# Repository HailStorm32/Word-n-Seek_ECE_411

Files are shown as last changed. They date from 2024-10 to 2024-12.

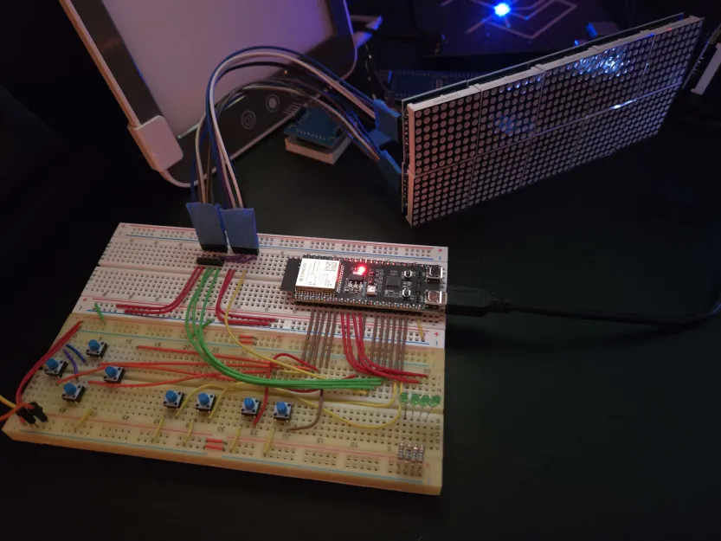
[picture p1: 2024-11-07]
Documents/Breadboard Prototype Photos/20241104_230953.webp

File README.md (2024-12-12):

## About

### Summary
This repo houses the code, board files, CAD files and documents for the ECE 411 course group project.

Word-n-Seek integrates a Wordle-style game into a small-sized arcade style gaming console, using a word retrieved from a Wordle-like API. This approach adds a unique dimension to the gameplay experience compared to using a phone or website.

The gameplay operates similarly to the popular Wordle game. Every day, the device will pull a new five-letter word from the API. The user has six attempts to guess the word, selecting letters with a buttons and confirming choices with selection keys. After each guess, the game marks correctly placed letters. The user continues guessing until either (a) they correctly guess the word or (b) they use all six attempts.

<p align="center">
Description
</p>

### Contributers
| Name | Contributions |
|---|---|
| [Bucanan Howard](https://github.com/BucananH) | PCB design and schematics developer, documentation and writing, soldering, and testing. |
| [Daniyil Kashkan](https://github.com/PeppyCode) | Documentation and writing lead, L1 diagram developer, power system design and construction, soldering, and testing. |
|[Demetri Van Sickle](https://github.com/HailStorm32) | Programming lead, GitHub and team manager, GPIO, display & game logic code. |
| [Mohammed Alreshoud](https://github.com/MohammedAlreshoud) | Documentation and writing, 3D design developer and console box constructor. |
| [Wallace McKenzie](https://github.com/Poly-guru)  | Programming, L0 diagram developer, Wordle API & Wi-Fi connection providing and testing. |

<br>

### Open Source Libs Used
- [max7219 Driver](https://github.com/UncleRus/esp-idf-lib/tree/master/components/max7219)
- [cJSON](https://github.com/DaveGamble/cJSON)

<br>
<br>

## Setup

### ESP-IDF Framework
Follow the directions on the [ESP-IDF wiki](https://docs.espressif.com/projects/esp-idf/en/v5.0/esp32s3/get-started/index.html#ide) on how to setup the environment

> Note: Use version 5.0 or greater

### "Wordle" API
Create a free account for the [Wordle Game API](https://rapidapi.com/azizbergach/api/wordle-game-api1) to gain an API key

> Note: the free tier only allows 60 requests/day

> Upgrading to the "pro" tier will allow for 5000 requests/day for $5

### Code
Code is under the `Code` directory. Open VS Code(or your preferred editor) in this directory for best results.

Create headers called `hidden.h` in the following directories and format as follows.

#### Components/apiControl/include

    #define  API_KEY  "api_key_string_here"

#### Components/wifiControl/include

    #define  WIFI_SSID  "ssid_string_here"
    #define  WIFI_PASS  "password_string_here"

<br>
<br>

## Use

### Buttons
Description

There are four small white directional buttons. Two for LEFT and RIGHT movement of the cursor. Press and hold either to slide the cursor left or right 
As well as two buttons for increasing and decreasing the screen brightness.

Four colored action buttons are to the right of the directional buttons, and are for SELECT, GUESS, DELETE and EXIT. These buttons will selectively light up when you are able to press them.

### Operation
Once the game starts, you will be able to add and delete letters to construct a five letter word (see [Modes](https://github.com/HailStorm32/Word-n-Seek#modes)). 

Once you are satisfied with your word guess, press GUESS to submit your word. The results screen on the bottom row will then update to display the which letters are correct (see [Results](https://github.com/HailStorm32/Word-n-Seek#results)). 

You have six guesses before the game ends. If you reach six guesses without guessing correctly, the results row will be replaced with what the word was supposed to be. The game is now over, press EXIT to exit.

If you guess the word before you use up all six guesses, the results screen will show all correct (see [Results](https://github.com/HailStorm32/Word-n-Seek#results)). The game is now over, press EXIT to exit.

### Modes

#### Startup
Once the device is powered up you will be greeted with the Word n Seek start screen. 

Press SELECT to start the game. Once the game is started, you will be in letter edit mode.

#### Edit Letters
Use the LEFT and RIGHT buttons to move the cursor left or right.

When the cursor is over the desired spot, press SELECT to enter letter select mode to place a letter at that spot, OR press DELETE to delete the selected letter.

#### Letter Selection
In this mode use the LEFT and RIGHT buttons to move the cursor and the letter carousel left and right.

Press SELECT to select the highlighted letter and return to letter edit mode.

Press DELETE to exit letter selection and return to letter edit mode without placing a letter.

### Results
In letter edit mode, the bottom row of the screen will show which letters are correct, incorrect, or are in the wrong place. Below are the possible symbols and what they mean.

#### Unknown
Description

State of letter is unknown
> Before your first guess, the result row will consist of all unknowns ('?')

#### Correct
Description

States that the letter is correct and in the right spot
<br>

#### Incorrect
Description

States that the letter is incorrect and not in the word
<br>

#### Swap
Description

States that the letter is correct, but in the wrong spot

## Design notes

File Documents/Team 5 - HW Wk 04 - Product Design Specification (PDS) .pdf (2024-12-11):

ECE 411
Andrew Greenberg
10/20/2024

## Team 5 Product Design Specification (PDS)

Bucanan Howard, Daniyil Kashkan, Demetrius Van Sickle, Mohammed Alreshoud, and Wallace McKenzie

Project Name

Word-n-Seek Game

Executive Summary with Concept of Operations

The Word-n-Seek design integrates a Wordle-style game into a small-sized arcade style gaming console, using a word retrieved from a Wordle-like API. This approach adds a unique dimension to the gameplay experience compared to using a phone or website.
The gameplay operates similarly to the popular Wordle game. Every day, the device will pull a five-letter word from the API. The user has six attempts to guess the word, selecting letters with arrow keys and confirming choices with selection keys. After each guess, the game marks correctly placed letters and removes incorrect letters. The user continues guessing until either (a) they correctly guess the word or (b) they use all six attempts.
Part of the screen will display a simplified “Wordle grid” with six rows (one per guess) and five columns (one per letter). The grid will use red, green, and blue to indicate incorrect, correct, and unguessed letters, respectively.

Market Analysis

The target customers for this product are casual gamers, word puzzle enthusiasts, and fans of Wordle who are seeking a console version they can use at their desk. Competition will come from smartphone apps, websites offering similar word puzzle games, and multi-purpose portable gaming consoles. This product distinguishes itself by offering a focused and immersive gaming experience through a physical device dedicated solely to playing Wordle. The novelty of a desktop game version of Wordle will appeal to both collectors and a casual audience much like similar tabletop arcade cabinets. Priced between $50 and $85, it remains affordable while incorporating essential components such as a screen, controllers, and Wi-Fi / Bluetooth modules. This makes it accessible to a wide audience while delivering a unique and enjoyable experience.

Requirements

- Must display words to the user.
- Must allow the user to add and delete letters.
- Must generate a new word to guess every day.
- Must have two forms of input.
- Must be able to turn on / off the device.
- Must not overheat on failure.
- Should have arrow keys.
- Should have multiple buttons.
- Should run off a 12V 2A DC supply.
- Should provide internal regulation to 5V 2A DC.
- Should have a timed mode.
- Should be able to broadcast the website for the user to configure Wi-Fi connection.
- May be portable, i.e., work as a desktop or handheld device.
- May shock the user on failure.
- May have a console box made of cedar, for the smell and aesthetics, or poplar, depending on expense.
- May have other game modes other than Wordle.
- May operate off battery power.
- May have a sleep mode.
- May have light-up buttons.
- May have an on/off switch.
- May give audible feedback in the form of tones / buzzes.

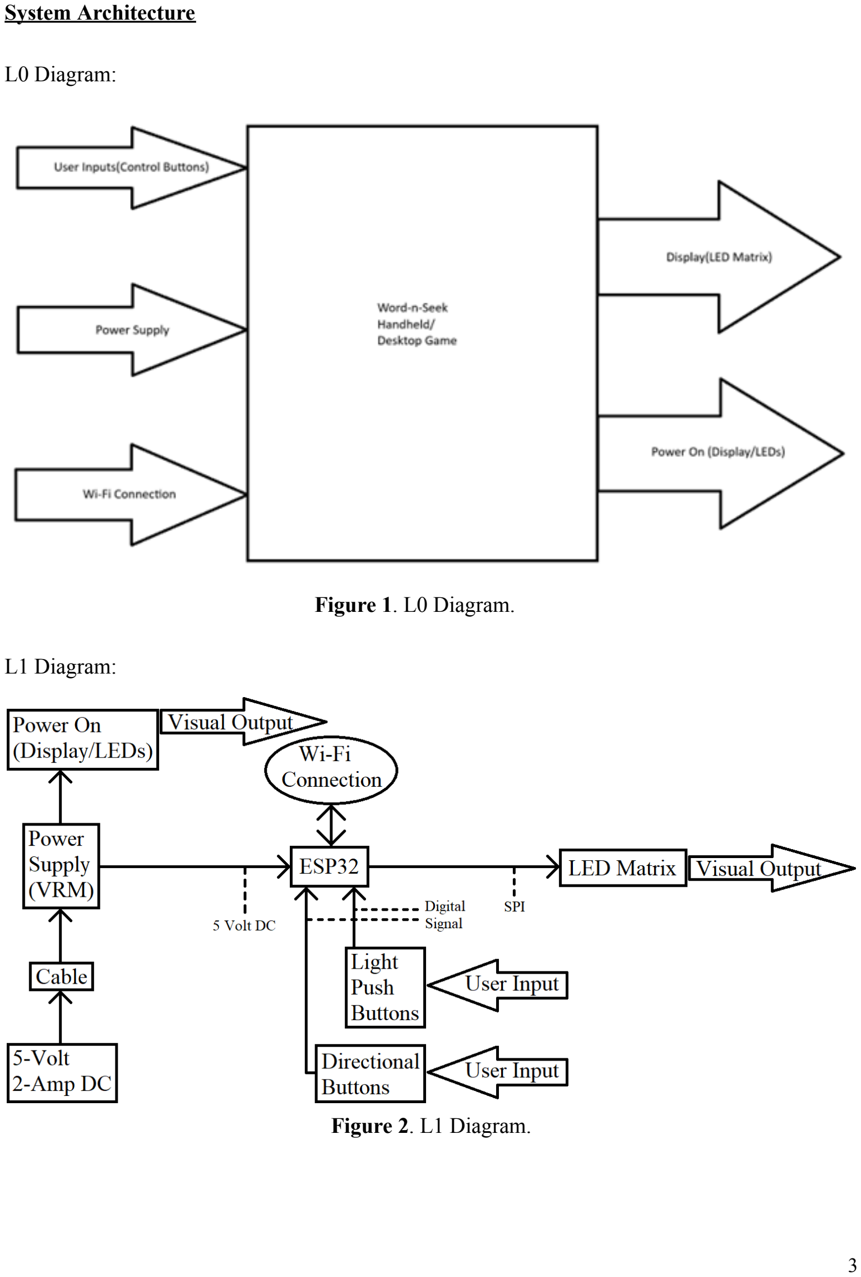
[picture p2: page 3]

System Architecture

L0 Diagram:

Figure 1. L0 Diagram.

L1 Diagram:

Figure 2. L1 Diagram.

Design Specification

Processor:

- ESP32-S3

Sensors:

- Arcade buttons
- Simple 4-way arrow key buttons
- No particular brand, there are a ton on Amazon.

Actuator:

- 10x EC Buying 8x8 LED matrix displays
- This particular display is driven by the max7219 chip and allows for easy daisy chaining of display modules. An LED matrix was chosen over an LCD panel due to time constraints and the available bandwidth of our team's coders. An LED matrix is easier to design graphics for than an LCD.

Power:

- 12V 2A DC regulated to 5V 2A DC

Development Environment:

- ESP-IDF framework

Enclosure:

- Wood or 3D-printed plastic case

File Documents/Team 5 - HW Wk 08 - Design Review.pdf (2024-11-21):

ECE 411
Andrew Greenberg
11/19/2024

## Team 5 Design Review

Bucanan Howard, Daniyil Kashkan, Demetrius Van Sickle, Mohammed Alreshoud, and Wallace McKenzie

First Design Review with Team 2 - 8:00 pm - 9:08 pm - Meeting Notes:

> Little to no negative feedback. PCB Traces look good. Everything looks straightforward.
> Positive feedback on the schematic design, with inquiries about its size and potential improvements. > Overall comment: “Good job!”
> Suggested to add switch main power rail.
> Should have 1uF labeled on decoupling cap on ESP32S3.
> Should add a note about having onboard USB on dev board.

Second Design Review with Team 7 - 9:30 pm - 10:11 pm - Meeting Notes:

> Voltage threshold 1.2 volts.
> Suggested labeling screen dimensions directly on the schematic for clarity and reference.
> Suggested labeling buttons on the schematic; e.g., |_ Adding "boxes" (label above buttons) > Add test points to the schematic??

Feedback for Team 5 (us) from Team 2

- GND should be labeled with 1.5 Farad (note for Bucanan).
- Label onboard USB for the PCB (also note for Bucanan).
- Overall no negative feedback, keep up the good work.
- Everything is straightforward, nothing extra or unnecessary.
- The on/off switch can be added directly to the PCB.
- However, Daniyil will stick with designing a separate circuit for testing purposes.

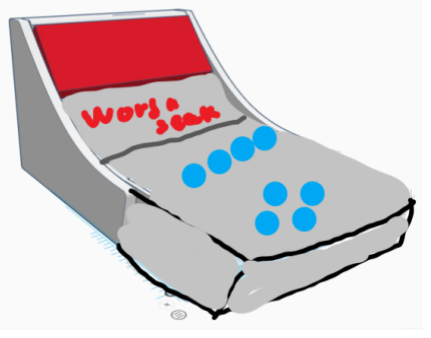
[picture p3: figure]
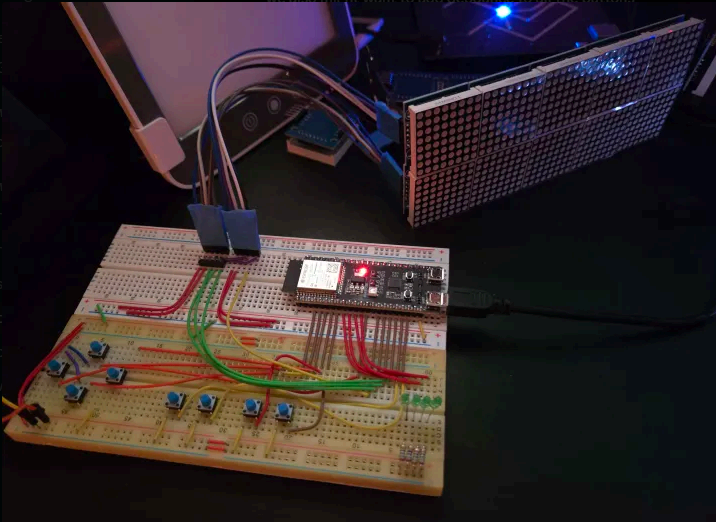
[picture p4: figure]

Figure 1. Figures shared by Team 5.

1

Feedback for Team 2 (from us to them)

- Pretty clear schematic to look at and ready.
- Specific roles defined. Every member seems caught up on the design and their own parts.
- The team also ran into plenty of problems, like proper power distribution.
- Resolved everything properly.
- Safeguards put into place like a power-off state in case of current issues.
- OLED ground makes sense, something else Bucanan found does not.
- Another OLED bit referenced questionably (NOT AN ISSUE).
- The battery can only be charged twice or three times.
- Systems are put into place to check fresh batteries against garbage batteries.
- Bucanan recommended adding fuses or Zener diodes to ensure proper 12 Volt flow (??)
- Last note: the buck converter handles most of the voltage regulation.
- The fan is always on. As long as the master switch is closed, the fan is on (always).
- It takes a couple hours to charge a battery (estimated 2 hours).
- You cannot push a battery too much while charging it, as it might break.
- Active high input. For safety, if the ESP32 fails, the active high input goes down.
- Recommendation by Bucanan: Implement a hardware failsafe.
- (exclusively software failsafes implemented now).
- List VTN for the transistors. Rename schematic ports for clarity.
- Add a current limiting diode between VCC and sensitive components.

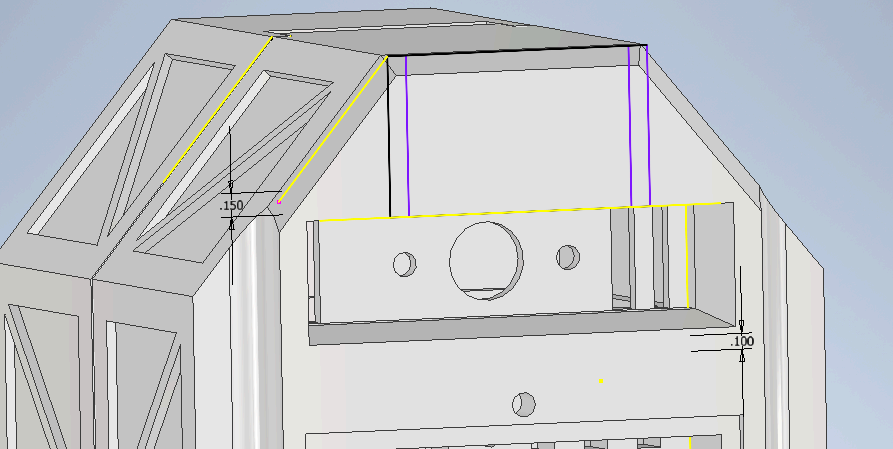
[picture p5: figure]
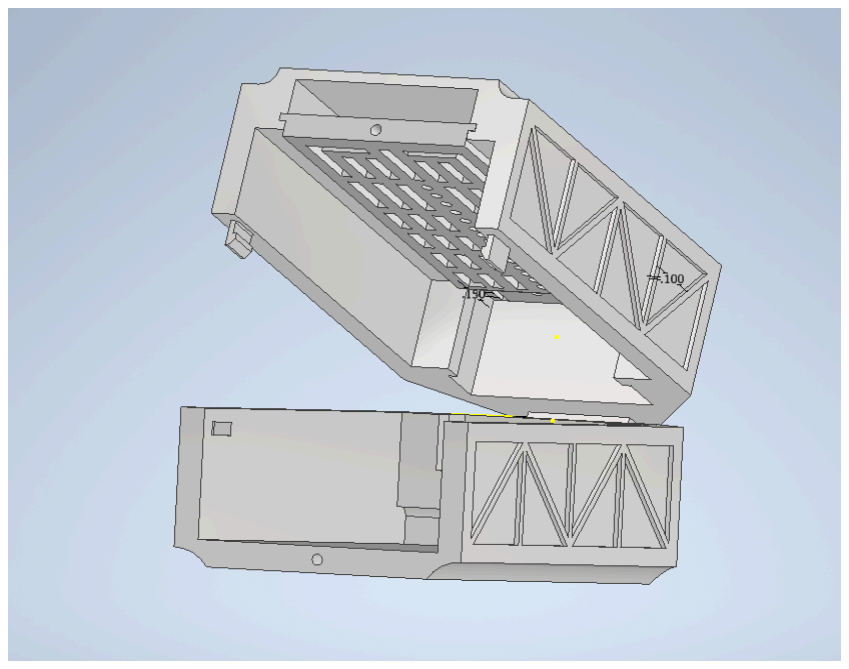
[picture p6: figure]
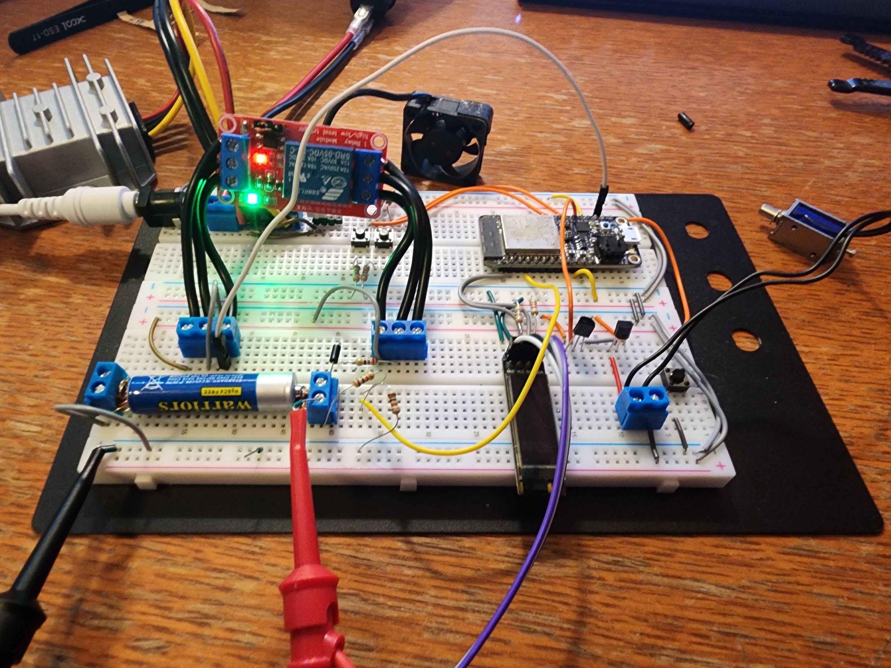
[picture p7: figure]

Figure 2. Figures shared by Team 2

Feedback for Team 5 (us) from Team 7

- Power distribution needs more defining.
- The threshold is 1.5V.
- Add a label above the buttons (recommended by Annika).

2

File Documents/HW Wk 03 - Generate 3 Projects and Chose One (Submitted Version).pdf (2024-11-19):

Bucanan Howard
Daniyil Kashkan
Demetrius Van Sickle
Mohammed Alreshoud
Wallace McKenzie
ECE 411
Andrew Greenberg
10/15/2024

Team 5 Practicum Project Progress Report: Generate Three Projects and Choose One

Three initial project ideas:
#1. Anti Drone Device (Drone Swatter)

#2. Air Filter System

#3. Handheld Wordle Game (Handle)

Descriptions of each project idea:

Project #1 Name: Anti Drone Device (Drone Swatter)
Project #1 Description:
Drone Swatter is a drone detection and deterrence system that uses targeted radio frequency (RF) analysis to identify and disrupt nearby drones by detecting telemetry signals commonly used for drone communication within the 2.4 GHz and 5 GHz frequency bands. When a drone is detected within a specified proximity, an alert is generated with an option to jam the drone’s control signal by broadcasting broadband white noise, temporarily disabling its operation by tampering with its pathfinding and connection.
Project #1 Concept of Operation:
Detection: The system remains idle while on and continuously scans for signals on 2.4 GHz and 5 GHz frequencies, typical of drone telemetry and control.
Telemetry Decoding: When a suspected drone signal is detected, the system attempts to decode its telemetry data to assess proximity and direction.
User Alert: If a drone is detected, the system alerts the user through an audible and visual signal. Optional Jamming: With user initiation, the system transmits a controlled broadband noise signal to jam drone control, providing a secure perimeter around sensitive areas.
Project #1 Components:
Sensors
1) Software-Defined Radio (SDR):
HackRF One: Well-suited SDR, covering a wide frequency range (1 MHz to 6 GHz), including both 2.4 GHz and 5 GHz bands, and allowing full-duplex communication. It will be the primary device for capturing telemetry signals, decoding data, and initiating detection protocols.

2) Antennas:
Dual-Band Antenna (2.4 GHz and 5 GHz): A single dual-band antenna enhances signal detection for both frequency bands, simplifying the design while ensuring coverage.
Yagi Directional Antenna: This directional antenna is used for precise detection and tracking of the drone’s approach direction, improving system responsiveness.
Controller
ESP32-S3 Microcontroller: The ESP32-S3 offers both Wi-Fi and Bluetooth capabilities, making it ideal for managing the SDR, performing initial signal processing, and controlling alert and jamming functions. It provides reliable data handling and control at a low cost, integrating well with the HackRF One and antennas.
Actuators
1) Broadband Noise Generator:
Mini-Circuits ZX93-2500+ Noise Source: This high-power noise source generates broadband white noise on the target bands (2.4 GHz and 5 GHz). Paired with the appropriate directional antennas, it provides efficient jamming capabilities when the user activates this mode.
2) Power Amplifier Module:
RF Power Amplifier (2.4 GHz and 5 GHz compatible): Boosts noise signal to ensure effective jamming within the desired radius, thus maintaining signal integrity during jamming.
3) User Alert System:
Buzzer: Emits audible alert when a drone is detected within range, ensuring prompt notification. LED Indicator Panel: Provides a visual signal strength indication, giving the user an immediate sense of proximity and detection status.

Project #2 Name: Air Filter System
Project #2 Description:
The purpose of the air filter system is to identify problems with air quality and initiate a dual filtration process to enhance the surrounding environment. To monitor air contaminants and modify the filtration rate accordingly, it uses a collection of sensors. With the help of an ESP32 microcontroller, the system can be operated automatically or by the user over Wi-Fi in real-time monitoring. The system has an LCD screen that provides real-time feedback on system status and air quality levels. Air is filtered through two layers of cloth.
Project #2 Concept of Operation:
Detection: The system continuously monitors the air for pollutants such as dust, gasses, and humidity. It remains idle until pollutant levels rise above a certain threshold.
Sensor Readings: Once a pollutant is detected, ESP32 reads data from the sensors and evaluates the air quality levels. The system determines whether filtration needs to be activated or adjusted. User Alert and Control: The system can alert the user via Wi-Fi notifications and display real-time air quality data on the LCD screen. The user can control the system manually or allow automatic filtration adjustment based on sensor data.

Filtration Control: The air is passed through two cloth filters, a coarse filter and a fine filter to remove larger particles and fine pollutants. The system dynamically adjusts the airflow using motor control relays based on the severity of contaminants. Filtration continues until safe air quality levels are restored.
Project #2 Components:
Sensors:
Air Quality Sensor (MQ-135): Detects various harmful gasses like CO2

, ammonia, and benzene.
Humidity and Temperature Sensor (DHT22): Monitors the air's humidity and temperature to adjust filtration speed and ensure optimal performance.
Controller:
ESP32 Microcontroller: Manages sensor data, processes air quality information, controls motor, provides Wi-Fi connectivity for remote monitoring, and communicates with the LCD screen. Actuators:
Fan Motor: Adjusts the airflow rate to filter out pollutants based on the sensor readings.
Relay Modules: Controls the activation and power levels of the filtration fan, allowing precise control over the filtering process.
Display Screen:
(16x2 or 20x4) LCD Display: Shows live air quality and pollutant levels, humidity, temperature, system status, and alerts. ESP32 refreshes data on this display continuously so that the user will have explicit visual feedback about air quality conditions.
Filtration Components:
Air Filter Cloth: First Layer: The first layer is the intake of air, which catches larger particles like dust, making it the front line of defense in the system.
Second Layer: It is at the air outlet and further strengthens the filtration by catching the finer particles to ensure only clean air is released.

Project #3 Name: Handheld Wordle Game (Handle)
Project #3 Description:
The Handheld Wordle Game would, in operation, take a word from the Wordle API and use it for a Wordle-style game built into a handheld gaming console. It brings a level of dimensionality to the phone game, and would enable us to add extra features to spice up Worlde itself. The game requires a built in screen, speakers, controllers/keyboard and a case. The system connects to the Wordle API either through Wi-Fi or through a phone Bluetooth connection and takes the daily Wordle word, which it then uses to play a word guessing game with the user.
Project #3 Concept of Operation:
Boot Up: Upon powering on the device, the handheld will prompt the user with the option to play today's Wordle game and to display their longest streak.
Getting Today's Wordle Word: After selecting to play a game, the ESP32 will use either Wi-Fi or bluetooth to connect to Wordle’s free API in order to grab a random five-letter word. The screen will then display five blank boxes.

Gameplay: Using the dials and keyboard, users will type a five-letter word and hit enter. The ESP32 will then compare that word against the daily word and use colored squares on the graphical display to communicate to the user which letters are incorrect, which letters are correct, and which letters are in the word but in the wrong spots.
Finishing the Game: Once the user guesses the word or runs out of chances, the game will end, and if the user was successful, the game will increase their win streak. If they fail, the streak will be reset instead.
Project #3 Components:
Sensors:
Push Button Switches: A switch network will be used to create a controller or keyboard interface that the user will utilize to interact with the game.
TE Connectivity / Alcoswitch: (https://www.mouser.com/manufacturer/alcoswitch/) A Potentiometer dial such as the TE Alcoswitch can be implemented in order to work as a selection wheel or menu scroll wheel.
Controller:
ESP32-S3 Microcontroller: The ESP32-S3 offers options for Wi-Fi and Bluetooth, both possible ways to connect to the Wordle API in order to get the daily word. The ESP32-S3’s flexibility and ease of programming will give us room to integrate both software and hardware features. Moreover, the non-volatile memory storage of the ESP32 will be beneficial in storing streaks and high scores.
Actuators:
Adafruit 1.9" 320x170 Color IPS TFT Display - ST7789: A colored screen is necessary for the functionality of a Wordle game, and the screen will show the number of remaining guesses, which letters are in the correct spots, and which letters are incorrect.
CVS-1508 Speakers: Add tactile sound feedback when a correct letter is selected, the word is guessed correctly, or the player loses the game.
28821 Coin Vibration Motor: A motor can be used to add a physical rumble feature to the game that, coupled with the sound, will provide a more exciting video-game experience for the user. Power:
9V Battery Snaps & Contacts 9V PCB MOUNT: The 9 volt battery casing attached to the back of the device will power the screen, ESP32, and sensors. A rechargeable 9 volt battery should provide enough mA hours to power the handheld for up to 6 hours.
DC-to-DC Converter: Not all modules on the board will require the same amount of power. So, where necessary, an appropriate DC-to-DC converter will be selected to meet those power needs.

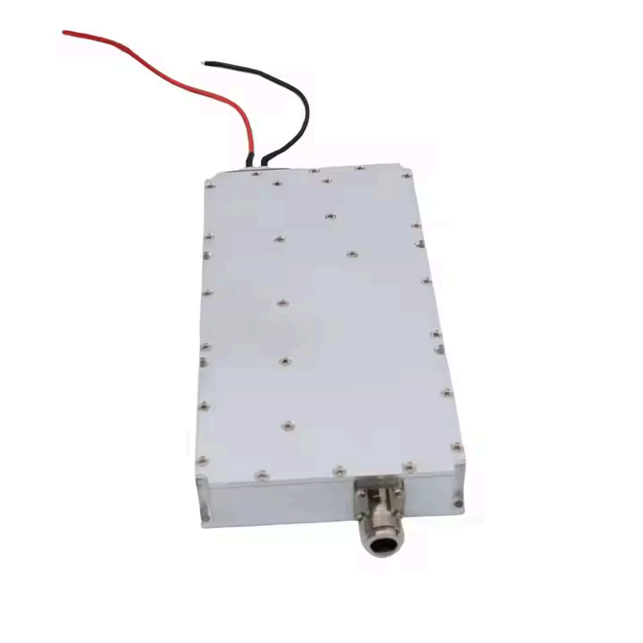
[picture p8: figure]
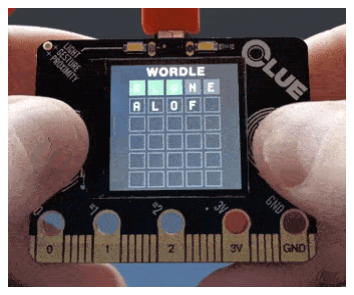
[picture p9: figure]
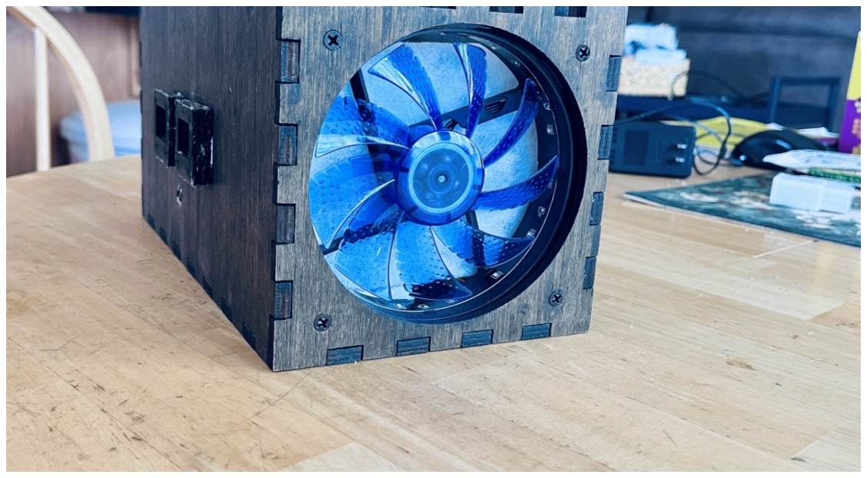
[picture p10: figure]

Figure 1. Project #1 | Figure 2. Project #2 | Figure 3. Project #3

Ultimately, the final project idea we have chosen to build is the Handheld Wordle Game. We passed on the Anti Drone Device project idea because it sounded too sophisticated and challenging to be completely implemented in the remaining seven weeks of the term, and it would require the availability of a drone which none of us have. We passed on the Air Filter System project idea because it did not sound challenging enough, as several members of the group already worked on similar projects, and a couple even designed and built air filter systems previously as part of the ECE 212 course. The Handheld Wordle Game is a new and unique project idea never designed by any team member, so it is an evenly fresh experience for us to implement using the disciplined design process taught in class and the available skills .

Finally, we came up with unique names: Handle for our project, Handle Builders for our team, and Handheld Wordle Game for our code repository.

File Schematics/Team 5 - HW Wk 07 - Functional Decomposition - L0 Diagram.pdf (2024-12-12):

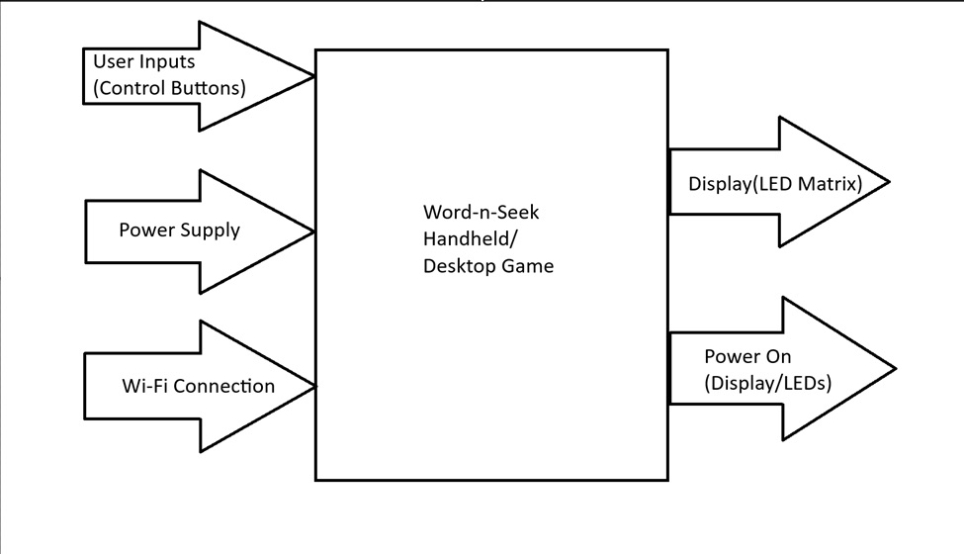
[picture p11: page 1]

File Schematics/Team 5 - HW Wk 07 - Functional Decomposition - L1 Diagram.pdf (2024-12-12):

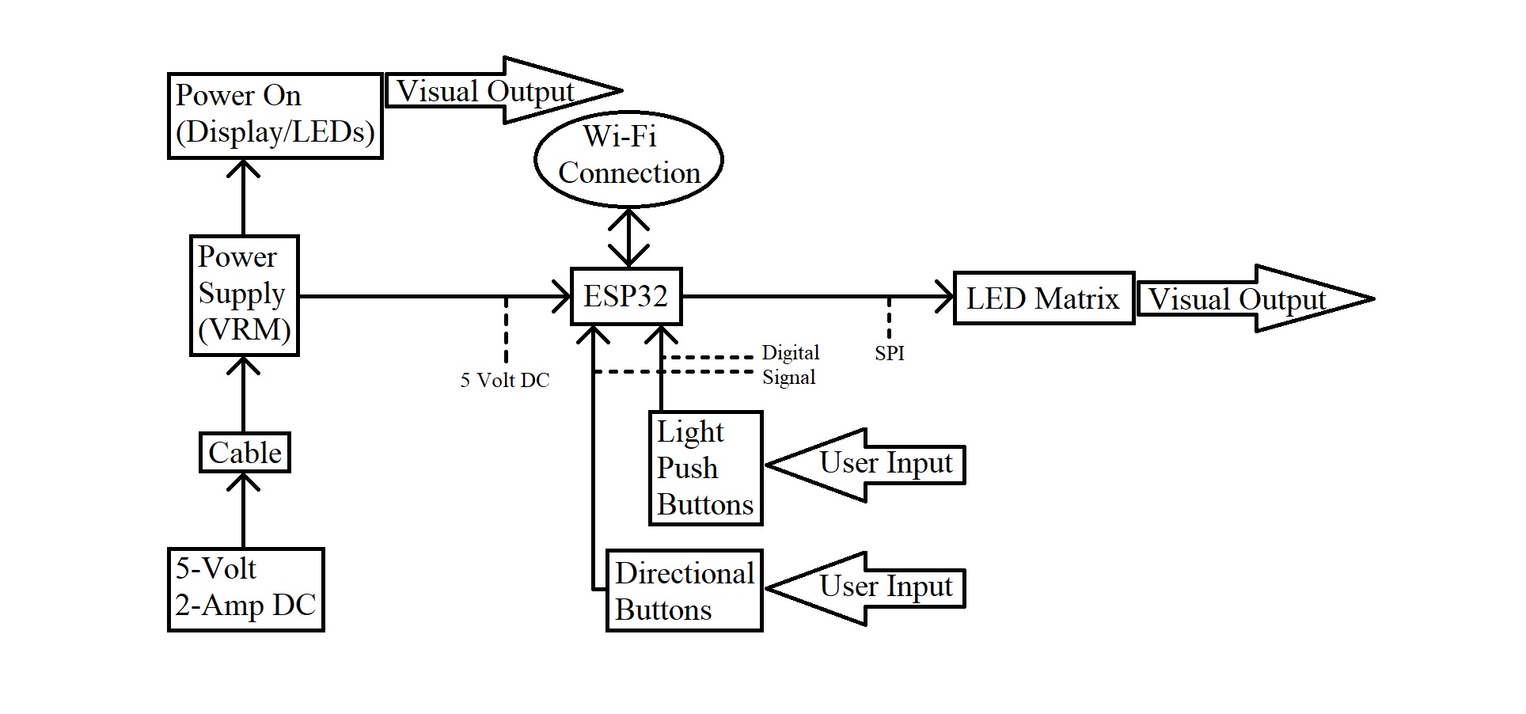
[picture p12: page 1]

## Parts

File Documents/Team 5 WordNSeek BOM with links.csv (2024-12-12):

# | Unique Name | P/NP | Manufacturer | Manufacturer Pin Number | Description | Distributor | Distributor Pin Number | Price Per Unit | Quantity | Total Cost | Link
1 | .1 uF Cap | P | Comchip | CAPP_0402_M | Capacitor | TAIYO YUDEN | 963-MAASL105CC7105MF | $0.10 | 2 | $0.20 | https://www.mouser.com/ProductDetail/TAIYO-YUDEN/MAASL105CC7105MFCA01?qs=HFfMDpzxxd1Fn%2FInbJA7vw%3D%3D
2 | 0603 Diode | P | Comchip | DIODE_0603 | Diode | TAIYO YUDEN | 750-CDBU0145-HF | $0.32 | 1 | $0.32 | https://www.mouser.com/ProductDetail/Comchip-Technology/CDBU0145-HF?qs=2qJf6qQ4IOKJ1QV5aOB4hg%3D%3D
3 | 5V 2A Power Supply | P | CUI INC | PJ-002A | Power supply barrel jack for DC power | Same Sky | 490-PJ-002A | $0.70 | 1 | $0.70 | https://www.mouser.com/ProductDetail/Same-Sky/PJ-002A?qs=WyjlAZoYn51CKfAix9Mngw%3D%3D&mgh=1&gad_source=1
4 | 5 pin Header | P | Samtec | TSW-105-23-G-S | Connector Header Through Hole 5 position 0.100 (2.54mm) | Samtec | 200-TSW10523GSLL | $0.58 | 10 | $5.80 | https://www.mouser.com/ProductDetail/Samtec/TSW-105-23-G-S-LL?qs=rU5fayqh%252BE0mHsi8oUSlPQ%3D%3D
5 | Jumper | P | Samtec | MTLW-101-24-G-D-210 | Connector Header Through Hole 2 position | Samtec | 200-MTLW10124GD210 | $0.48 | 3 | $1.44 | https://www.mouser.com/ProductDetail/Samtec/MTLW-101-24-G-D-210?qs=rU5fayqh%252BE2sZjyn6To4eg%3D%3D
6 | 7 Nmos Stack | P | TI | DRV777DR | 20-V, 7- bit Integrated Motor and Relay Driver | Texas Instruments | 595-DRV777DR | $0.48 | 1 | $0.48 | https://www.mouser.com/ProductDetail/595-DRV777DR
7 | ESP32 | P | Espressif | ESP32-S3-DEVKITC-1-N8R2 | WiFi Development Tools - 802.11 (Engineering Samples Only) ESP32-S3 General-Purpose Development Board, ESP32-S3-WROOM-1-N8R2, with Pin Header | Espressif Systems | 356-E32-S3DVKTC1N8R2 | $15.00 | 1 | $15.00 | https://www.mouser.com/ProductDetail/Espressif-Systems/ESP32-S3-DevKitC-1-N8R2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
8 | 8x8 MAX7219 Dot Matrix Display | P | EC Buying | N/A | 8x8 Dot Matrix Display | Amazon | N/A | $1.08 | 10 | $10.80 | https://a.co/d/9yggITk
9 | 24mm LED Illuminated Push Button | P | EG Starts | N/A | 24mm LED Illuminated Push Button | Amazon | N/A | $2.40 | 5 | $12.00 | https://a.co/d/87GFwCD
10 | 30mm LED Illuminated Push Button | P | EG Starts | N/A | 30mm LED Illuminated Push Button | Amazon | N/A | $2.38 | 5 | $11.90 | https://a.co/d/aKY7UUA
11 | 3-D Printed enclosure | P | EPL | N/A | 3-D Printed (enclosure) - Multiple parts | EPL | N/A | $38.24 | 1 | $38.24
12 | PCB | P | OSH park | N/A | Our PCB design | OSH park | N/A | $30.13 | 1 | $30.13
 |  |  |  |  |  |  |  |  | Total Cost: | $127.01

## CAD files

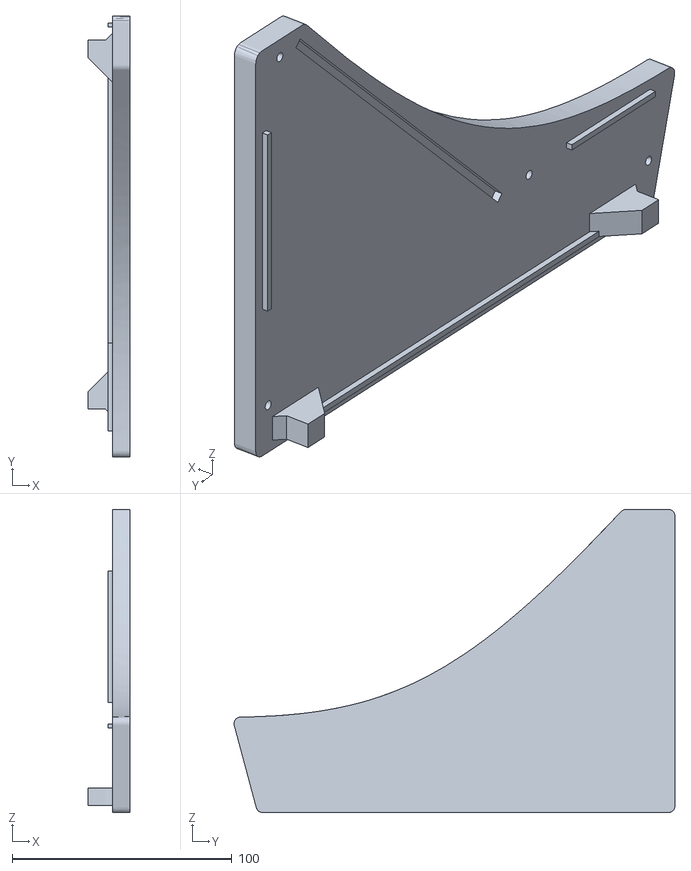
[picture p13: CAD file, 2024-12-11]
3D_Closure/Right_panel.stl
19.0 x 200.7 x 138.0

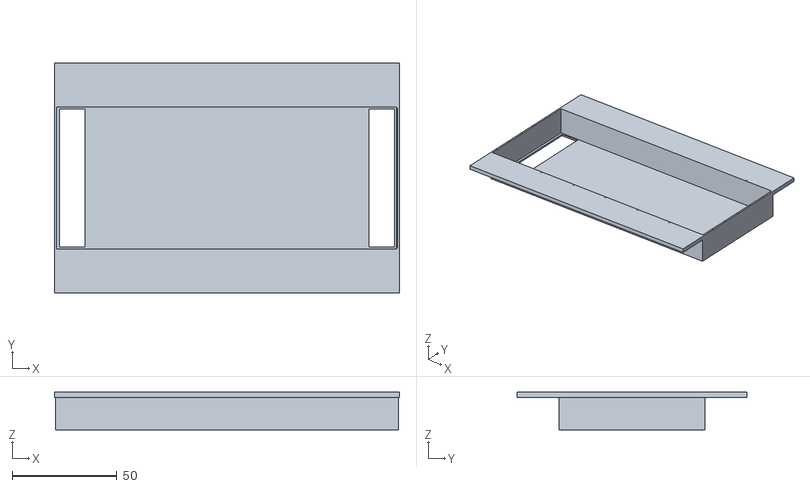
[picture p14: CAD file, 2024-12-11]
3D_Closure/ScreenMountVer2.stl
165.0 x 110.0 x 18.0

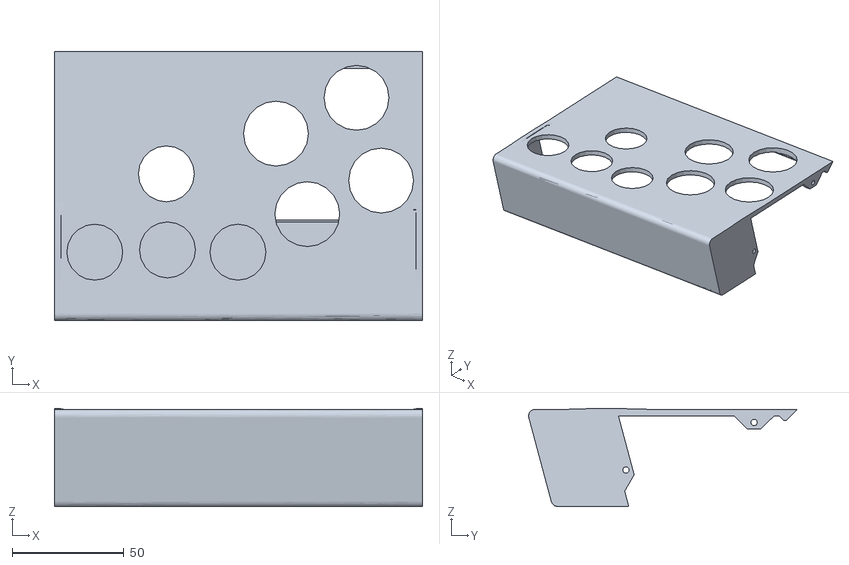
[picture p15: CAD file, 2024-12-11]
3D_Closure/Controller_ver2.stl
164.5 x 120.1 x 43.8

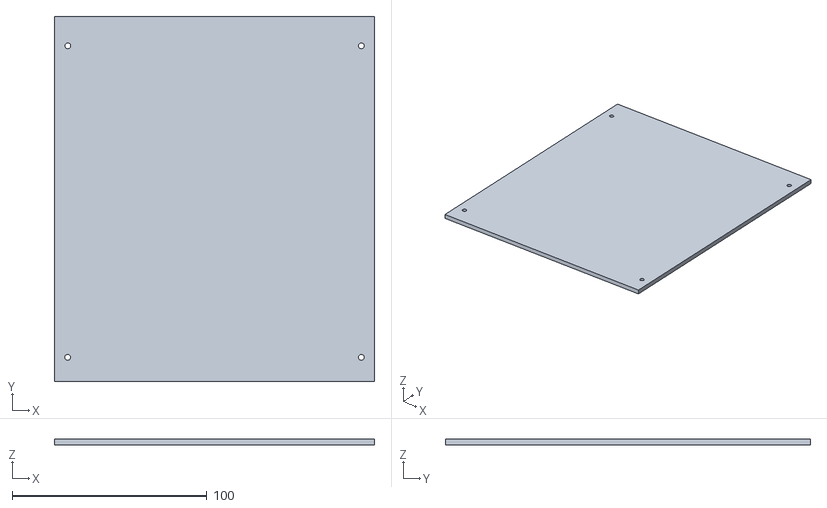
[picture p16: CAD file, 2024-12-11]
3D_Closure/Bottom_panel.stl
164.5 x 187.8 x 3.00

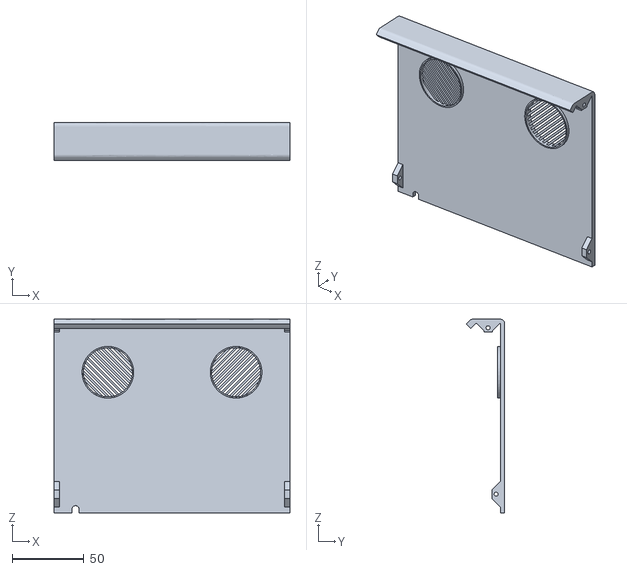
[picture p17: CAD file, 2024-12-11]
3D_Closure/Back panel.stl
164.5 x 26.8 x 135.0

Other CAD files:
3D_Closure/Left_panel.stl

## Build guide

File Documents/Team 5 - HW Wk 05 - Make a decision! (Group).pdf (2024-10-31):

ECE 411
Andrew Greenberg
10/27/2024

## Team 5 Make a Decision Assignment

Bucanan Howard, Daniyil Kashkan, Demetrius Van Sickle, Mohammed Alreshoud, and Wallace McKenzie

1. To choose a proper display for our project design, we use the Decision Matrix and Analytical Hierarchy Process (AHP) methodologies as tools to make a final decision based on the types of displays and desired characteristics.
2. Decision Matrix:

The matrix in Figure 1 shows the comparison of five display options across six criteria: Brand Name, Cost, Safety, Design, Power Consumption, and Ease of Coding. Each option is rated and weighted to produce a final score.

| Medium 16x32 RGB LED matrix panel - 6mm Pitch (Adafruit) | 0.91 inch OLED I2C SSD1306 LED DC Display (Arduino) | 2.8" SPI TFT LCD Display Touch Panel ILI9341 240x320 (XIITIA) | 10x 8x8 LED matrix display (EC Buying) | I2C IIC 1602 LCD Display Module 16x02 (Hosyond)
Brand-name | 1 | 5 | 5 | 2 | 4 | 3
Cost | 3 | 1 | 5 | 2 | 3 | 4
Safety | 2 | 4 | 3 | 3 | 4 | 3
Design | 5 | 4 | 3 | 4 | 4 | 4
Power Consumption | 4 | 3 | 1 | 1 | 5 | 1
Ease of Coding | 5 | 5 | 1 | 1 | 5 | 1
Score | | 73 | 50 | 43 | 86 | 50
Figure 1. Decision Matrix.

3. AHP:

The table in Figure 2 shows pairwise comparisons among criteria to establish their relative importance, resulting in weights that reflect each criterion’s priority in the decision process.

Figure 2. Analytical Hierarchy Process (AHP).

The expanded Decision Matrix in Figure 3 evaluates each display option under each criterion using AHP pairwise comparisons, generating a ranking based on the weighted criteria.

| Medium 16x32 RGB LED matrix panel - 6mm Pitch (Adafruit) (https://www.adafruit.com/product/420) | 0.91 inch OLED I2C SSD1306 LED DC Display (Arduino) (https://www.amazon.com/HiLetgo-Serial-Display-SSD1306-Arduino/dp/B01N0KIVUX) | 2.8" SPI TFT LCD Display Touch Panel ILI9341 240x320 (XIITIA) (https://www.amazon.com/XIITIA-Display-ILI9341-240x320-Screen/dp/B0CJHTMPXF) | 10x 8x8 LED matrix display (EC Buying) (https://www.amazon.com/EC-Buying-MAX7219-Electronic-Microcontroller/dp/B0BXDNCVRT) | I2C IIC 1602 LCD Display Module 16x02 (Hosyond) (https://www.amazon.com/Hosyond-Display-Module-Arduino-Raspberry/dp/B0BWTFN9WF?th=1)
Brand-name | 0.12 | 0.371 | 0.028 | 0.054 | 0.438 | 0.11
Cost | 0.09 | 0.10 | 0.38 | 0.12 | 0.19 | 0.21
Safety | 0.21 | 0.21 | 0.20 | 0.19 | 0.21 | 0.19
Design | 0.05 | 0.22 | 0.44 | 0.15 | 0.09 | 0.11
Power Consumption | 0.26 | 0.44 | 0.11 | 0.22 | 0.09 | 0.15
Ease of Coding | 0.27 | 0.15 | 0.22 | 0.44 | 0.11 | 0.09
Score | | 0.26 | 0.19 | 0.24 | 0.17 | 0.14
Figure 3. Expanded Decision Matrix.
| Brand-name | Cost | Safety | Design | Power Consumption | Ease of Coding | Mean | Weight
Brand-name | 1 | 7 | 1/9 | 2 | 1/2 | 1/2 | 0.9 | 0.12
Cost | 1/7 | 1 | 2 | 2 | 1 | 1/9 | 0.6 | 0.09
Safety | 9 | 1/2 | 1 | 2 | 1/2 | 2 | 1.4 | 0.21
Design | 1/2 | 1/2 | 1/2 | 1 | 1/9 | 1/5 | 0.4 | 0.05
Power Consumption | 2 | 1 | 2 | 9 | 1 | 1 | 1.8 | 0.26
Ease of Coding | 2 | 9 | 1/2 | 5 | 1 | 1 | 1.9 | 0.27
Fraction values are in the Calc sheet (https://docs.google.com/spreadsheets/d/1eQpPgmgjUxQAnvneXPUD6lUV1ERm-a3i-iPEuT672x0/edit?gid=1924139799) | | | | | | | | 1.00

| Medium 16x32 RGB LED matrix panel -6mm Pitch (Adafruit) | 0.91 inch OLED I2C SSD1306 LED DC Display (Arduino) | 2.8" SPI TFT LCD Display Touch Panel ILI9341 240x320 (XIITIA) | 10x 8x8 LED matrix display (EC Buying) | I2C IIC 1602 LCD Display Module 16x02 (Hosyond) | Brand name rating
Medium 16x32 RGB LED matrix panel -6mm Pitch (Adafruit) | 1 | 7 | 5 | 1 | 7 | 0.371
0.91 inch OLED I2C SSD1306 LED DC Display (Arduino) | 1/7 | 1.00 | 1/5 | 1/7 | 1/7 | 0.028
2.8" SPI TFT LCD Display Touch Panel ILI9341 240x320 (XIITIA) | 1/5 | 5 | 1 | 1/9 | 1/5 | 0.054
10x 8x8 LED matrix display (EC Buying) | 1 | 7 | 9 | 1 | 9 | 0.438
I2C IIC 1602 LCD Display Module 16x02 (Hosyond) | 1/7 | 7 | 5 | 1/9 | 1 | 0.11

Figure 4. Finalized AHP based on the display options.

4. The results from the Decision Matrix and finalized AHP show that the 10x 8x8 LED matrix display (EC Buying) is the preferred display option for our project. Thus, we got the same result from both the Decision Matrix and the AHP methodologies.

In evaluating the display options, we focused on six key criteria: Brand Name, Cost, Safety, Design, Power Consumption, and Ease of Coding, each weighted to fit our technical and project needs. Brand Name was considered for reliability and ease of support, but it held less weight than direct performance factors. Cost had a moderate weight, allowing us to stay within budget without sacrificing essential features. Safety took into account factors like durability and electrical protection, scoring higher for displays with added resilience. Design influenced the display’s usability and fit within the project, with considerations for screen clarity, size, and ease of physical integration. Power Consumption was highly prioritized, as efficient power usage is essential for battery-operated projects, and alternatives were scored based on current draw and power-saving capabilities. Ease of Coding was weighted heavily, as it affects development time and integration reliability, so displays that offered robust libraries and compatibility with our programming environment scored higher. This balance of criteria helped us pick a display that meets both our technical requirements and practical constraints.

To come up with the tables, we followed the recommendations to use Google Sheets and insert the tables into a Google Doc. The Google Sheet tables can be found by following this link: https://docs.google.com/spreadsheets/d/1eQpPgmgjUxQAnvneXPUD6lUV1ERm-a3i-iPEuT672x0/edit?gid=0#gid=0. (https://docs.google.com/spreadsheets/d/1eQpPgmgjUxQAnvneXPUD6lUV1ERm-a3i-iPEuT672x0/edit?gid=0#gid=0)

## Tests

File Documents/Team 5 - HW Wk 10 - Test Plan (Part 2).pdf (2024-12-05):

Test Case

Test Author: Team 5
Test Case Name: | Power Supply Testing | Test ID #: | PS-TC-01
Description: | Using Bifurcation, and a current limited lab power supply use the onboard jumpers to safely test power delivery to all sections of the circuit | Type: | □ white box □ black box □ ________

Tester Information
| Name of Tester: | Bucanan Howard | Date: | 12/4/24
| HW/SW Version: | Ver 4/ Ver 1.0 | Time: | 6:00 PM
| Setup: | Variable PSU, board with buttons and display
S T E P | Action | Expected Result | P A S S | F A I L | N / A | Comments
1 | No Jumpers, Barrel Jack Plugged in | 5 V on cathode of the diode | das
2 | Jumper to ESP32 plugged in | 5V at Power pin of ESP 32, current draw increased | ass
3 | Jumper to Screens Plugged in | Screens power on, current draw increased | asd | | | Reset required to see image on screen
4 | Plug in Select Button | Onboard LED on buttons turns on | | 123 | | Vcom on Nmos stack incompatible with power supply
5 | Probe Button signal pin in | 3.3 volts on each button data pin | 123
6 | Connect all jumpers and start game | Display lights up at full brightness as do button LEDs | | 1233 | | Increase current limit to 250 mA Pass on re-test
| Overall test result: | | 123 | | | Core functionalities power as specced, hardware change required for the button LEDs
2024-12-04 | Page 1 of 3

Matrix Test (for varying parameters)

Test Author: Team 5

Test Case Name: | Directional Button Functions | Test ID #: | DB-MT-01
Description: | Test that the 4 directional buttons function as intended. | Type: | □ white box □ black box □ _____________

Tester Information

| Name of Tester: | Demetri Van Sickle | Date: | 12/4/24
| HW/SW Version: | 4.0/1.0 | Time: | 6:40pm
| Setup: | 4 directional buttons, main board, 5V supply, display
T E S T | INPUTS | EXPECTED OUTPUTS | P A S S | F A I L | N / A | Comments
1 | Select button pressed at reboot | Start screen transitions to game screen | 12
2 | Select button pressed at game | Select screen entered | 12
3 | Exit Button Pressed | Game exits | 12
4 | Left Button Pressed | Cursor scrolls left | 12
5 | Right Button Pressed | Cursor scrolls right | 12
6 | Up Button Pressed | Screen Brightness Increases | 12 | | | Double check schematic for silk screen assignments
7 | Down Button Pressed | Screen Brightness Decreases | 12
| Overall test result: | | 12

Test Case

Test Author: Team 5
Test Case Name: | On/Off Switch Testing | Test ID #: | SW-TC-02
Description: | Test that the voltage regulator correctly regulates all incoming voltage to output 5 Volts DC, that the on/off switch properly functions and activates and/or deactivates the ESP32 based on its position, and that the LEDs provide proper feedback for incoming wall voltage connection and switch position. | Type: | □ white box □ black box □ ________

Tester Information
| Name of Tester: | Daniyil Kashkan | Date: | 12/4/24
| HW/SW Version: | Ver 4/ Ver 1.0 | Time: | 7:20 PM
| Setup: | 12V cable converter, 5V voltage regulator, LEDs with resistors, on/off switch (7101J1V3QE2 C&K)
S T E P | Action | Expected Result | P A S S | F A I L | N / A | Comments
1 | Plug Cable into a 120V AC Wall Socket | 120V AC converted to 5V 2A DC; first LED lights up | das | | | Converted to 12V 2A DC, which is acceptable
2 | Flip the Switch Position | Closes or opens the connection; second LED turns on/off | das
3 | Probe Voltage Regulator | Takes in 12V (from step 1), outputs 5V at all times | asd | | | Minimum of 7V input required
4 | Probe the ESP32 | Turns on when switch is closed and off when switch is opened | das | | | Requires 7V min for proper 5Vin
5 | Disconnect Wall Socket Cable | The entire device, including both LEDs, shuts off | das
| Overall test result: | | das | | | All tests correctly passed, switch circuit ready to be applied to the rest of the device

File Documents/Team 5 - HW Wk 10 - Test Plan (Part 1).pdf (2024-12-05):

ECE 411
Andrew Greenberg
12/01/2024

## Team 5 Test Plan

Bucanan Howard, Daniyil Kashkan, Demetrius Van Sickle, Mohammed Alreshoud, and Wallace McKenzie

# Part 1

### Unit Tests

- Test power supply provides 5V
- Test ESP32-S3 powers on
- Test WiFi module powers up
- Test that all matrix displays powerup
- Test that when buttons are pressed it pulls the input to GND
- On/Off switch test

### Verification Tests

- Test SELECT button starts new game on powerup
- Test SELECT button selects letter under cursor
- Test LEFT button moves the cursor left
- Test RIGHT button moves the cursor right
- Test DELETE button deletes letter under cursor in letter edit mode
- Test the WiFi module that it connects and disconnects
- Test the LED module on the matrix lights up
- Test the game if it detects winning or losing

### Validation Tests

- Test if SELECT button switches to letter select mode when pressed in letter edit mode
- Test if SELECT button switches to letter edit mode when pressed in letter edit mode
- Test GUESS button submits word for verification from either letter edit or letter select mode
- Test DELETE button only functions when in letter edit mode
- Test EXIT button quits the game from any mode
- Test the game ends when all attempts have been used the display will show you the correct solution
- Test the system accurately tracks the number of attempts
- Test the system if it automatically advances to the next round after a win or a loss

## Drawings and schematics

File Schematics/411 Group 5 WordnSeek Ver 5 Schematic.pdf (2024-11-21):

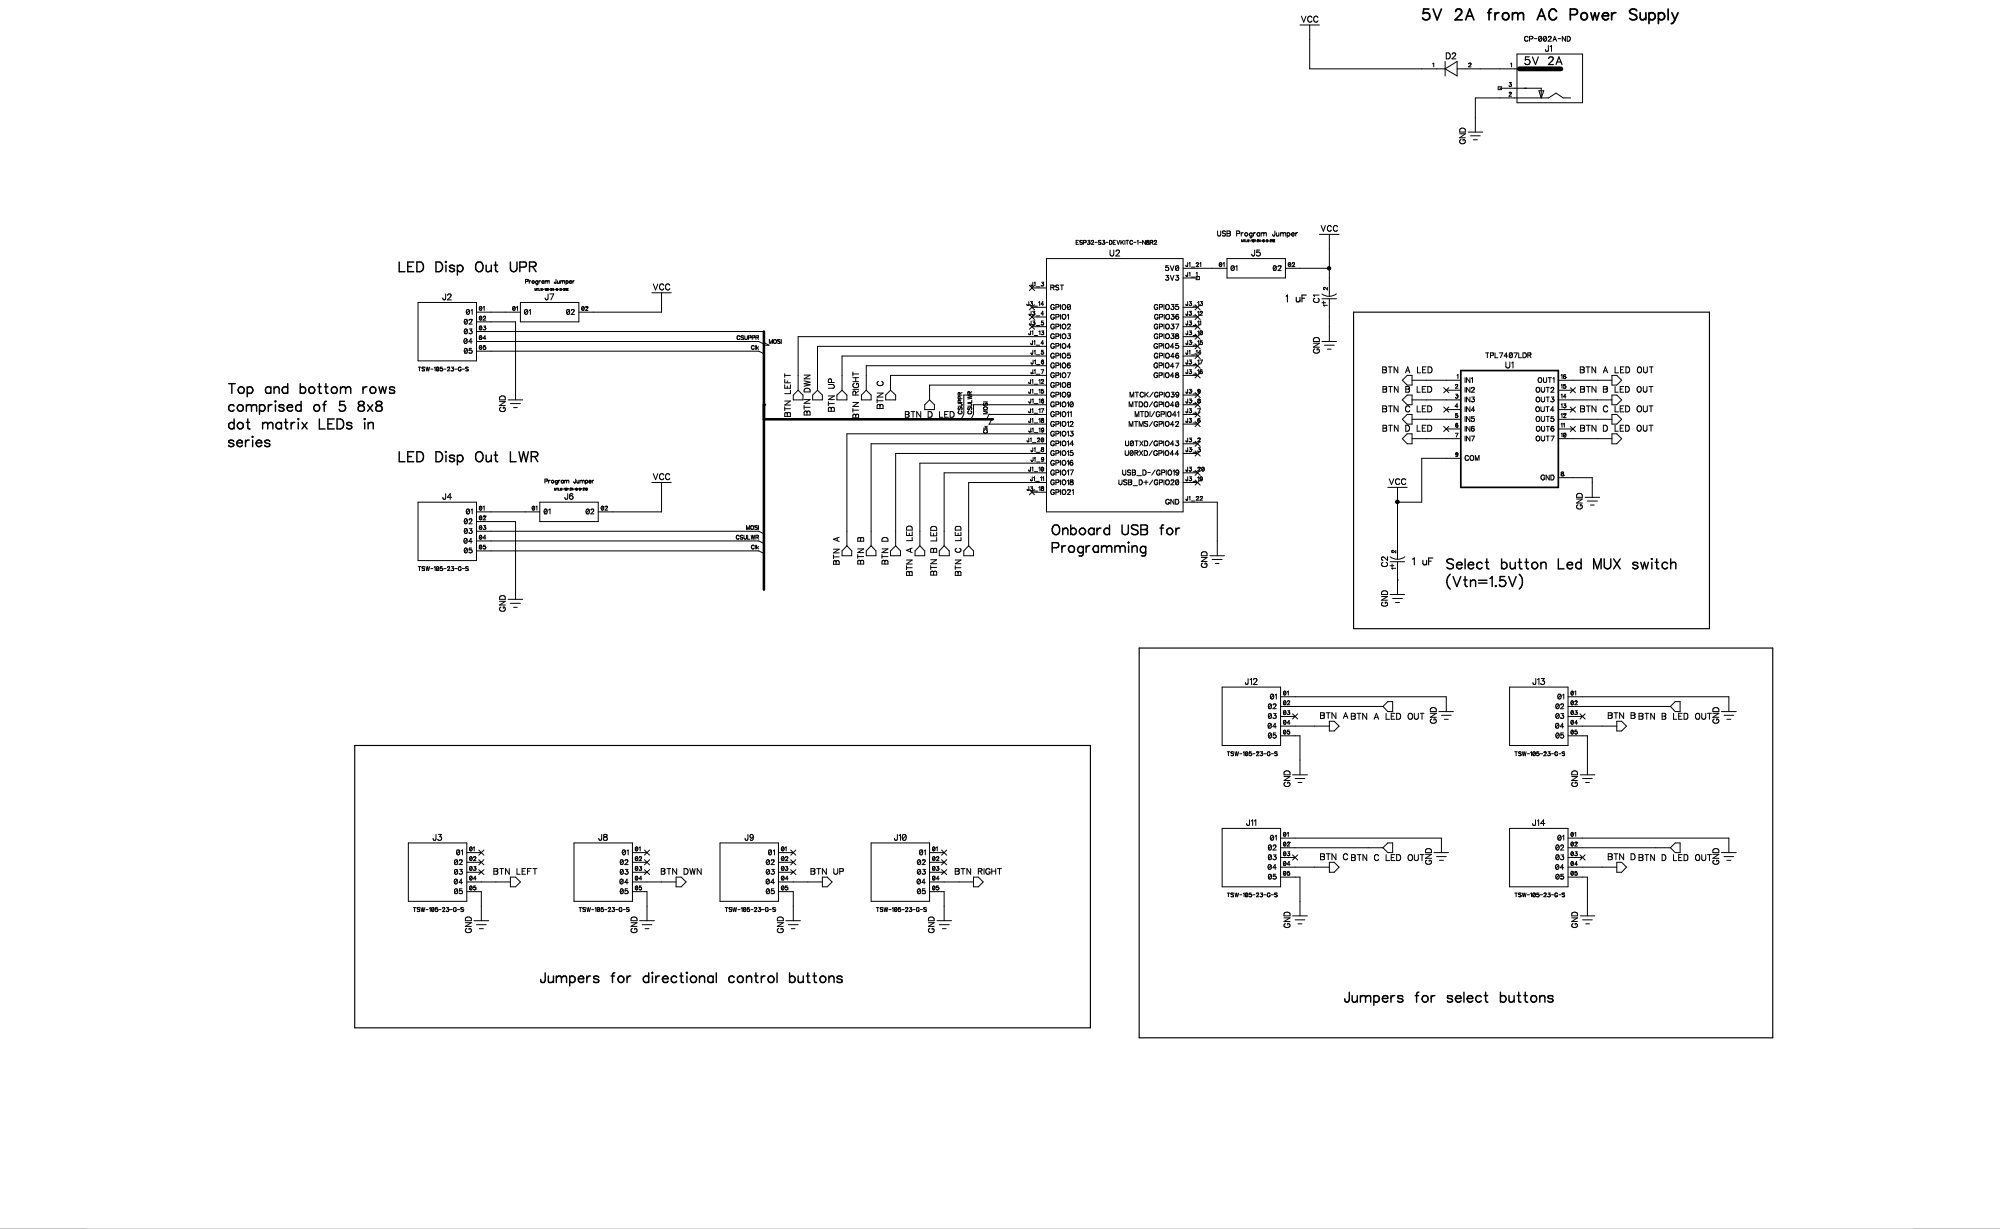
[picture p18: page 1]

Top and bottom rows
comprised of 5 8x8
series

BTN BBTN B LED OUTGND

BTN DBTN D LED OUT

Jumpers for select buttons

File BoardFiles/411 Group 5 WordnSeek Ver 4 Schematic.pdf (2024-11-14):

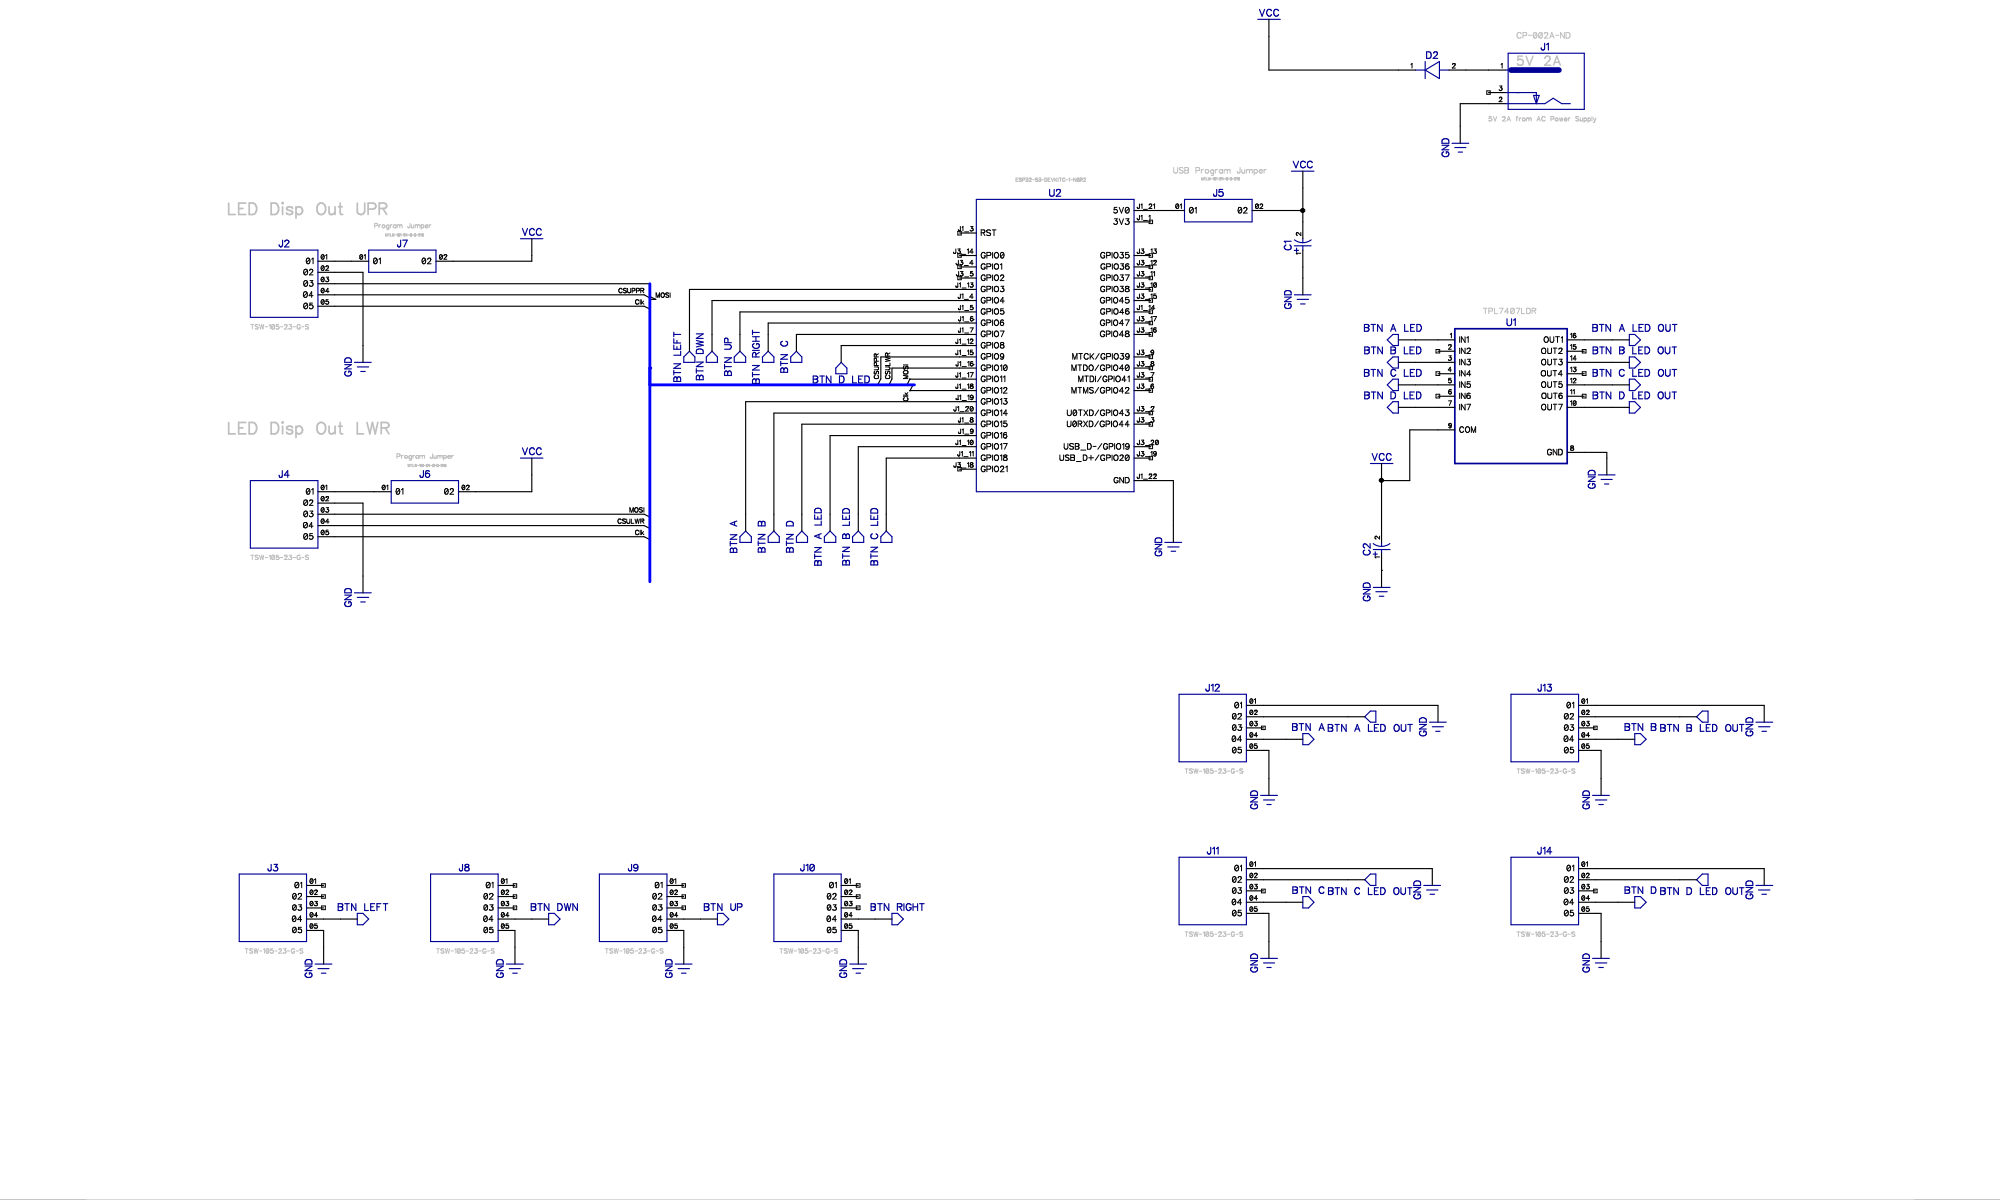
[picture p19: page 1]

5V 2A from AC Power Supply

BTN BBTN B LED OUTGND

BTN DBTN D LED OUT

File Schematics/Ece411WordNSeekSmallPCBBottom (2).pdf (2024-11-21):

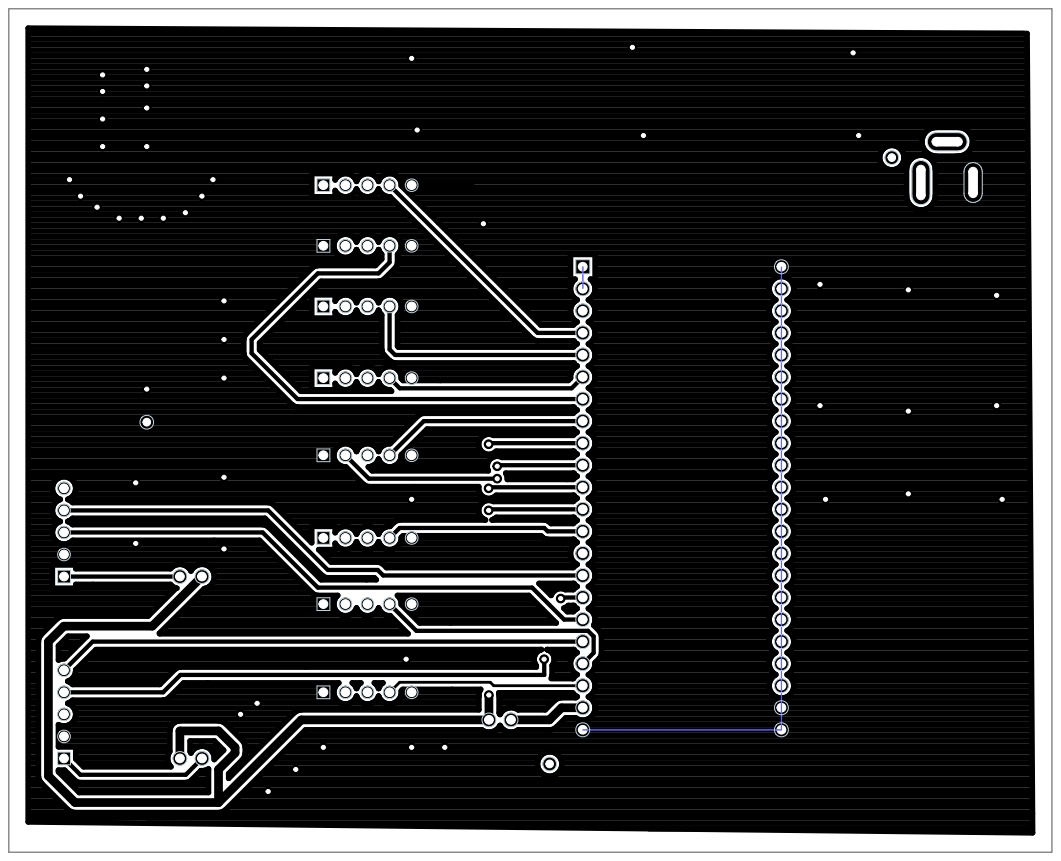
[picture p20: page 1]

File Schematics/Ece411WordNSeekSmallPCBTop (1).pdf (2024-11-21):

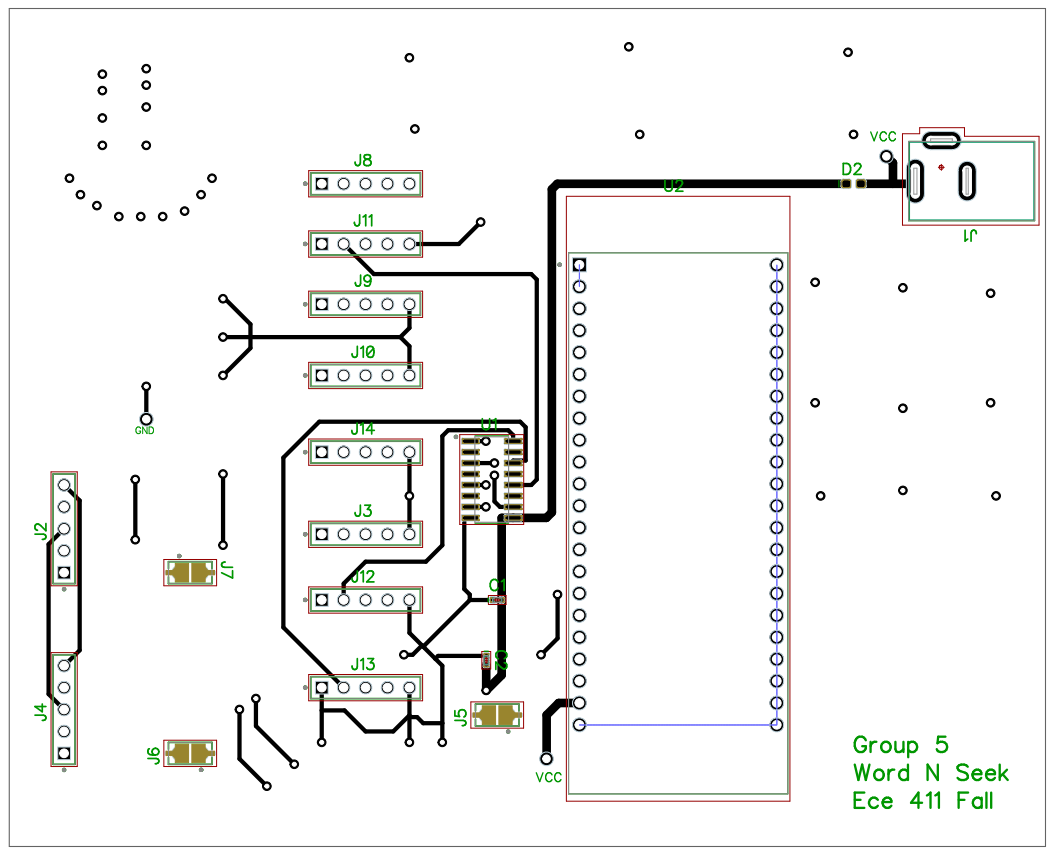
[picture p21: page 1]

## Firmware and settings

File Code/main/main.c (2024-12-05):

#include "esp_log.h"
#include <gpioControl.h>
#include <wifi.h>
#include "api_client.h"
#include <matrixDisplay.h>
#include <wordGuessGame.h>

#define LOG_TAG  "main"

int app_main(void)
{
    initGPIO();
    ESP_LOGI(LOG_TAG, "ESP32 WiFi Station");
    wifi_init_sta();
    api_client_init();
    display_init();  
    ESP_LOGI(LOG_TAG, "Boot successful");
    
    wordGuessGameStart();

    return 0;
}

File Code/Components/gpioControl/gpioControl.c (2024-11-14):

#include "esp_log.h"
#include "gpioControl.h"

/*-----------------------------------------------------------
Literal Constants
------------------------------------------------------------*/

//Create a bit masks to select the GPIO pins we want
#define GPIO_OUTPUT_PIN_SEL ((1ULL<<GPIO_BTN_A_LED) | (1ULL<<GPIO_BTN_B_LED) | (1ULL<<GPIO_BTN_C_LED) | (1ULL<<GPIO_BTN_D_LED))
#define GPIO_INPUT_PIN_SEL  ((1ULL<<GPIO_JOY_LEFT) | (1ULL<<GPIO_JOY_RIGHT) | (1ULL<<GPIO_JOY_UP) | (1ULL<<GPIO_JOY_DOWN) | (1ULL<<GPIO_BTN_A) | (1ULL<<GPIO_BTN_B) | (1ULL<<GPIO_BTN_C) | (1ULL<<GPIO_BTN_D))

#define ESP_INTR_FLAG_DEFAULT 0

#define DEBOUNCE_TIME_MS 200


#define LOG_TAG "gpio_control"


/*-----------------------------------------------------------
Macros
------------------------------------------------------------*/

#define TICKS_TO_MS(ticks) (ticks * portTICK_PERIOD_MS)

/*-----------------------------------------------------------
Types
------------------------------------------------------------*/

/*-----------------------------------------------------------
Gobals
------------------------------------------------------------*/

QueueHandle_t gpioEventQueue = NULL;

/*-----------------------------------------------------------
Statics
------------------------------------------------------------*/

uint64_t s_lastTime;

/*-----------------------------------------------------------
Local Function Prototypes
------------------------------------------------------------*/

static void IRAM_ATTR gpioIsrHandler(void* arg)
{
    uint32_t gpio_num = (uint32_t) arg;
    uint64_t curMS = TICKS_TO_MS(xTaskGetTickCountFromISR());

    //To debounce the button, we will only send the event if the last event was more than DEBOUNCE_TIME_MS ago
    if(curMS - s_lastTime > DEBOUNCE_TIME_MS)
    {
        xQueueSendFromISR(gpioEventQueue, &gpio_num, NULL);
    }

    s_lastTime = curMS;
}

/*-----------------------------------------------------------
Functions
------------------------------------------------------------*/

esp_err_t initGPIO()
{
    gpio_config_t ioConf = {}; 
    esp_err_t ret = ESP_OK;

    //initialize the timer
    s_lastTime = 0;

    //disable interrupt
    ioConf.intr_type = GPIO_INTR_DISABLE;
    //set as output mode
    ioConf.mode = GPIO_MODE_OUTPUT;
    //bit mask of the output pins
    ioConf.pin_bit_mask = GPIO_OUTPUT_PIN_SEL;
    //disable pull-down mode
    ioConf.pull_down_en = 0;
    //disable pull-up mode
    ioConf.pull_up_en = 0;
    //configure GPIO with the given settings
    ret |= gpio_config(&ioConf);

    //interrupt of rising edge
    ioConf.intr_type = GPIO_INTR_NEGEDGE;
    //bit mask of the input pins
    ioConf.pin_bit_mask = GPIO_INPUT_PIN_SEL;
    //set as input mode
    ioConf.mode = GPIO_MODE_INPUT;
    //enable pull-up mode
    ioConf.pull_up_en = 1;
    ret |= gpio_config(&ioConf);

    if(ret != ESP_OK)
    {
        ESP_LOGE(LOG_TAG, "Error setting up GPIO pins");
        return ret;
    }
    
    //create a queue to handle gpio event from isr
    gpioEventQueue = xQueueCreate(10, sizeof(uint32_t));

    //install gpio isr service
    ret |= gpio_install_isr_service(ESP_INTR_FLAG_DEFAULT);

    //hook up isr handler for each pin
    ret |= gpio_isr_handler_add(GPIO_JOY_LEFT, gpioIsrHandler, (void*) GPIO_JOY_LEFT);
    ret |= gpio_isr_handler_add(GPIO_JOY_RIGHT, gpioIsrHandler, (void*) GPIO_JOY_RIGHT);
    ret |= gpio_isr_handler_add(GPIO_JOY_UP, gpioIsrHandler, (void*) GPIO_JOY_UP);
    ret |= gpio_isr_handler_add(GPIO_JOY_DOWN, gpioIsrHandler, (void*) GPIO_JOY_DOWN);
    ret |= gpio_isr_handler_add(GPIO_BTN_A, gpioIsrHandler, (void*) GPIO_BTN_A);
    ret |= gpio_isr_handler_add(GPIO_BTN_B, gpioIsrHandler, (void*) GPIO_BTN_B);
    ret |= gpio_isr_handler_add(GPIO_BTN_C, gpioIsrHandler, (void*) GPIO_BTN_C);
    ret |= gpio_isr_handler_add(GPIO_BTN_D, gpioIsrHandler, (void*) GPIO_BTN_D);

    if(ret != ESP_OK)
    {
        ESP_LOGE(LOG_TAG, "Error setting up GPIO ISRs");
        return ret;
    }

    return ret;
}

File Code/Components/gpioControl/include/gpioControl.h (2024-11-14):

#pragma once

#include <stdbool.h>
#include "driver/gpio.h"
#include "freertos/FreeRTOS.h"
#include "freertos/queue.h"

//Define the GPIO pins we want to use
#define GPIO_JOY_LEFT   3
#define GPIO_JOY_RIGHT  6
#define GPIO_JOY_UP     5
#define GPIO_JOY_DOWN   4
#define GPIO_BTN_A      13
#define GPIO_BTN_B      14
#define GPIO_BTN_C      7
#define GPIO_BTN_D      15

#define GPIO_BTN_A_LED 16 
#define GPIO_BTN_B_LED 17
#define GPIO_BTN_C_LED 18
#define GPIO_BTN_D_LED 8

extern QueueHandle_t gpioEventQueue;

/*
* Description:
*      sets up the GPIO pins
*
* Arguments:
*      None
*
* Returns:
*      true -- if the GPIO pins were successfully set up
*      false -- if the GPIO pins were not successfully set up
*/
esp_err_t initGPIO();

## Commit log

2024-10-15 Add files via upload
    Here is my suggestion the pcb design program and to get myself listed as a contributor.
2024-10-31 Add files via upload
    Preliminary schematic for work and seek
2024-11-07 Second Version Word N Seek Schematic and prelim layout
2024-11-07 Create Team 5 - HW Wk 06 - Show off Your Breadboard Prototype (Group).pdf
2024-11-14 added L0 and L1 diagrams to Schematics
2024-11-18 Team 5 BOM with links
    [Team 5 WordNSeek BOM with links.xlsx]
2024-11-18 Create Team 5 WordNSeek BOM with links CSV Version.csv
    [Team 5 WordNSeek BOM with links CSV Version.csv]
2024-11-18 added CSV version of BOM
    added CSV version of BOM
    [Team 5 WordNSeek BOM with links.csv]
2024-11-18 Team 5 BOM CSV
    [Team 5 WordNSeek BOM with links_attempt1.csv, Team 5 WordNSeek BOM with links_attempt2.csv]
2024-11-19 Created new BOM in csv format
    [Team 5 WordNSeek BOM with links - Team 5 WordNSeek BOM.csv]
2024-11-19 Cleaned up BOM file
    [Team 5 WordNSeek BOM with links - Team 5 WordNSeek BOM.csv, Team 5 WordNSeek BOM with links.xlsx, Team 5 WordNSeek BOM with links_attempt1.csv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]
2024-11-19 Removed old BOM track
    [Team 5 WordNSeek BOM.csv]
2024-11-19 Renamed BOM file
    [Team 5 WordNSeek BOM with links.csv]
2024-11-19 Fixed spelling in BOM
    [Team 5 WordNSeek BOM with links.csv]
2024-11-19 Removed line 8 a test line
    [Team 5 WordNSeek BOM with links.csv]
2024-11-19 Moving the schematics to a single file to allow for version tracking through git
2024-11-19 Added new base Schematic
2024-11-19 Updated Schematic to version 4
2024-11-19 Updated BOM
    [Team 5 WordNSeek BOM with links.csv]
2024-12-11 Moved BOM into Documents
    [Team 5 WordNSeek BOM with links.csv]
2024-12-12 BOM Finalized
    [Team 5 WordNSeek BOM with links.csv]
